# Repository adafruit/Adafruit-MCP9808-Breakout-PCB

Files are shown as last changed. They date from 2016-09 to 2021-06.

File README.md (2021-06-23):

## Adafruit MCP9808 High Accuracy I2C Temperature Sensor Breakout PCB
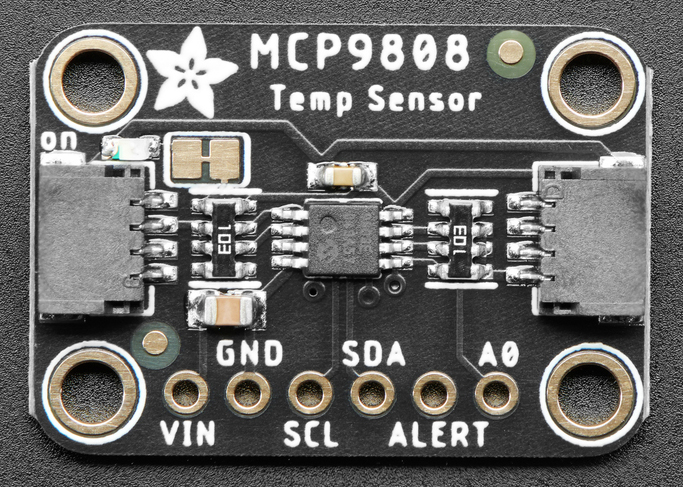
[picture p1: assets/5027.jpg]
<a href="http://www.adafruit.com/products/5027"><br/>
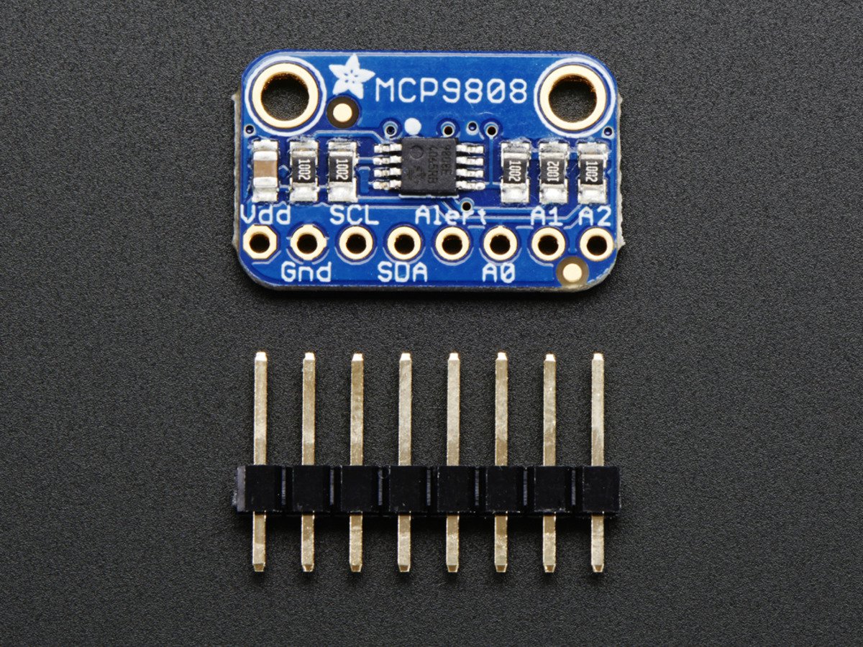
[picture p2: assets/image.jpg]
<a href="http://www.adafruit.com/products/1782"><br/>
Click here to purchase one from the Adafruit shop</a>

This I2C digital temperature sensor is one of the more accurate/precise we've ever seen, with a typical accuracy of ±0.25°C over the sensor's -40°C to +125°C range and precision of +0.0625°C. They work great with any microcontroller using standard i2c. There are 3 address pins so you can connect up to 8 to a single I2C bus without address collisions. Best of all, a wide voltage range makes it usable with 2.7V to 5.5V logic!

Unlike the DS18B20, this sensor does not come in through-hole package so we placed this small sensor on a breakout board PCB for easy use. The PCB includes mounting holes, and pull down resistors for the 3 address pins. We even wrote a lovely little tutorial and library that will work with Arduino or CircuitPython. You'll be up and running in 15 minutes or less.

PCB files for the Adafruit MCP9808 Breakout. The format is EagleCAD schematic and board layout
- https://www.adafruit.com/products/1782

### License

Adafruit invests time and resources providing this open source design, please support Adafruit and open-source hardware by purchasing products from [Adafruit](https://www.adafruit.com)!

All text above must be included in any redistribution

Designed by Limor Fried/Ladyada for Adafruit Industries.
Creative Commons Attribution/Share-Alike, all text above must be included in any redistribution. 
See license.txt for additional information.

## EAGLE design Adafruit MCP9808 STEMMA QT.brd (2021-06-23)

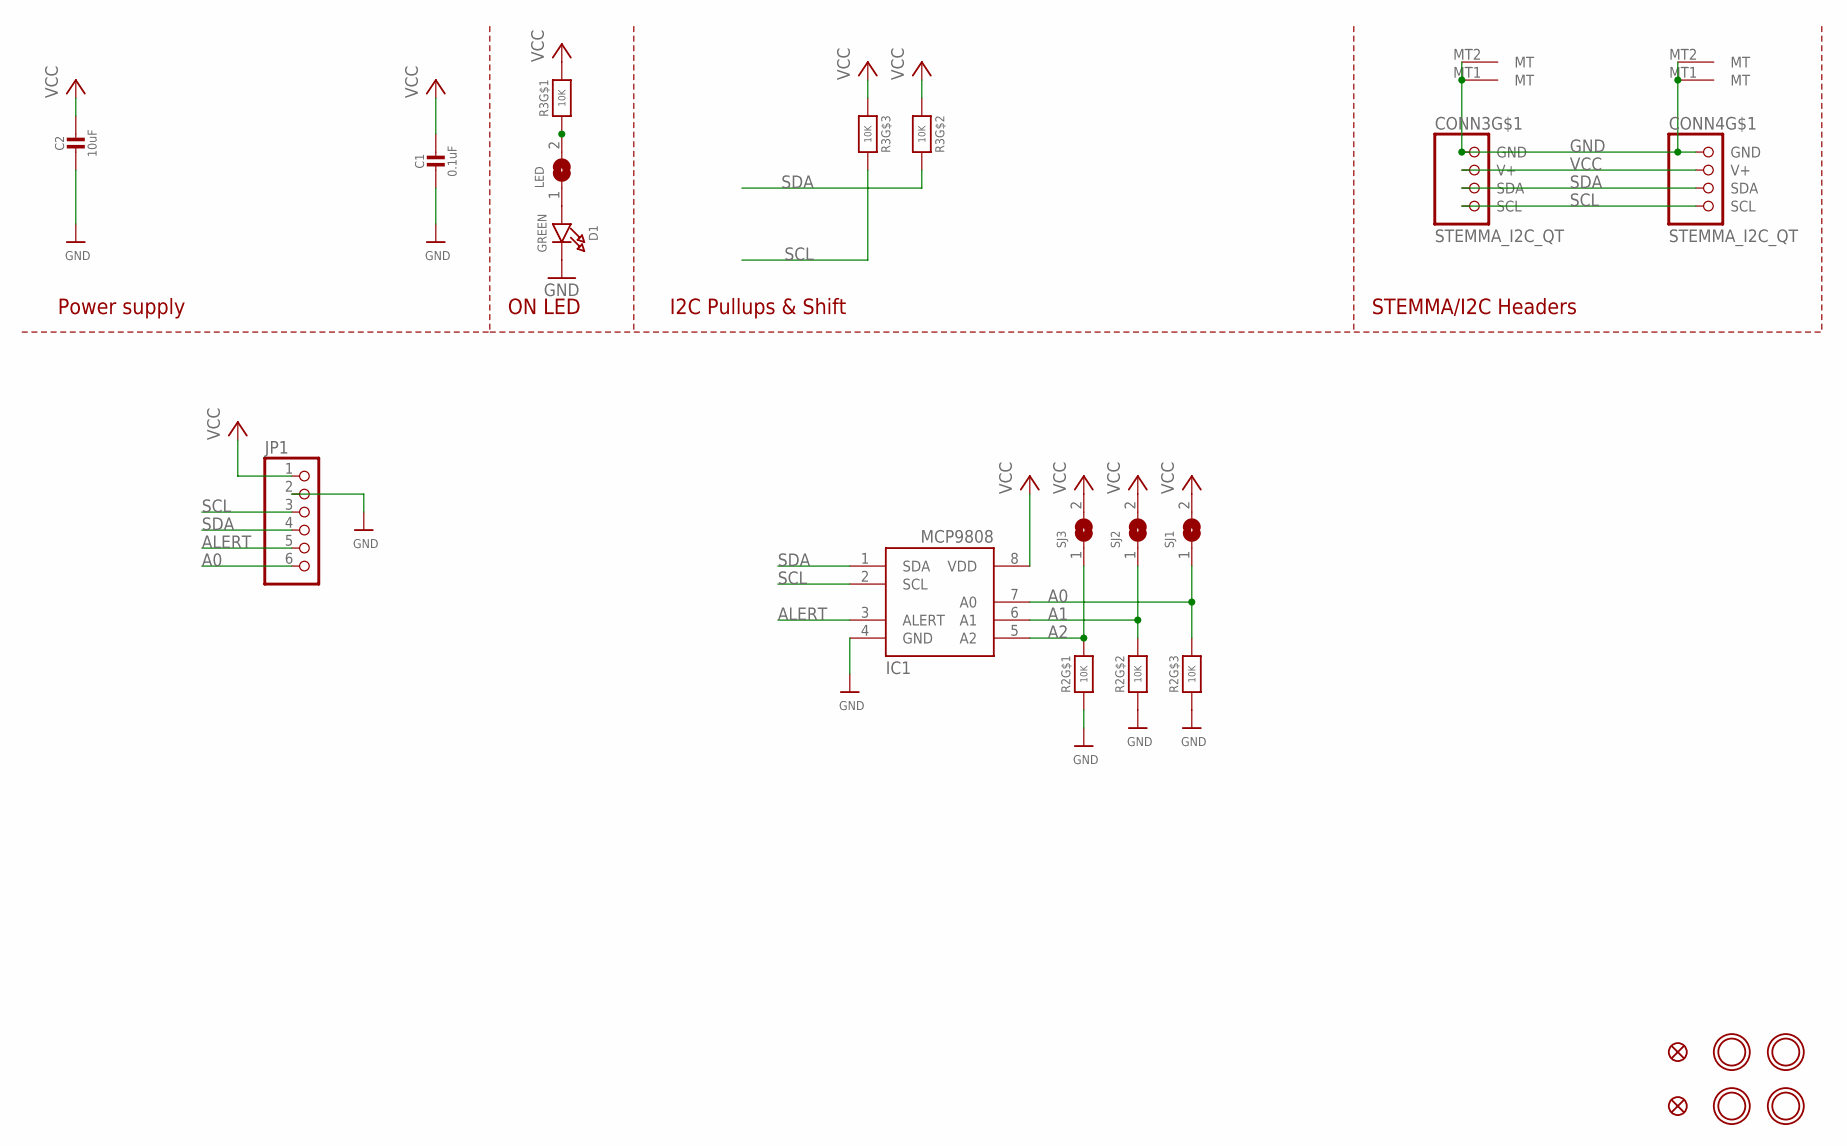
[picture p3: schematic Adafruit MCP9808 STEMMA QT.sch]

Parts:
C1: 0.1uF; 0603-NO
C2: 10uF; 0805-NO
CONN3, CONN4: STEMMA_I2C_QT; JST_SH4
D1: GREEN; CHIPLED_0603_NOOUTLINE
FID3, FID4: FIDUCIAL_1MM
IC1: MCP9808-E/MS; MSOP8_0.65MM
JP1: HEADER-1X670MIL; 1X06_ROUND_70
LED: SOLDERJUMPERCLOSED; SOLDERJUMPER_CLOSEDWIRE
R2, R3: 10K; RESPACK_4X0603
SJ1, SJ2, SJ3: SOLDERJUMPER; SOLDERJUMPER_ARROW_NOPASTE
U$1, U$17, U$19, U$21: MOUNTINGHOLE2.5; MOUNTINGHOLE_2.5_PLATED

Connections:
A0: IC1.7 (A0), JP1.6, R2.6 (2), SJ1.1
A1: IC1.6 (A1), R2.7 (2), SJ2.1
A2: IC1.5 (A2), R2.8 (2), SJ3.1
ALERT: IC1.3 (ALERT), JP1.5
GND: C1.2, C2.2, CONN3.1 (GND), CONN3.MT1 (MT), CONN3.MT2 (MT), CONN4.1 (GND), CONN4.MT1 (MT), CONN4.MT2 (MT), D1.C, IC1.4 (GND), JP1.2, R2.1, R2.2 (1), R2.3 (1)
unnamed: LED.2, R3.1
unnamed: D1.A, LED.1
SCL: CONN3.4 (SCL), CONN4.4 (SCL), IC1.2 (SCL), JP1.3, R3.6 (2)
SDA: CONN3.3 (SDA), CONN4.3 (SDA), IC1.1 (SDA), JP1.4, R3.7 (2)
VCC: C1.1, C2.1, CONN3.2 (V+), CONN4.2 (V+), IC1.8 (VDD), JP1.1, R3.2 (1), R3.3 (1), R3.8 (2), SJ1.2, SJ2.2, SJ3.2

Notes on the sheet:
I2C Pullups & Shift
STEMMA/I2C Headers
ON LED
Power supply

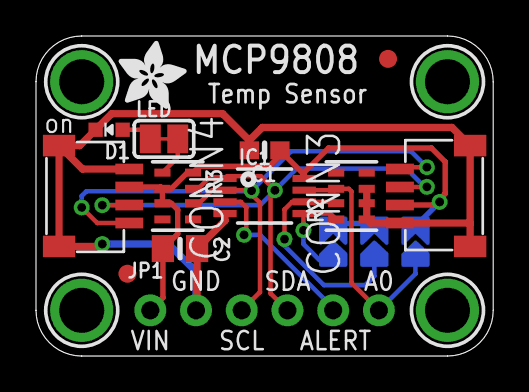
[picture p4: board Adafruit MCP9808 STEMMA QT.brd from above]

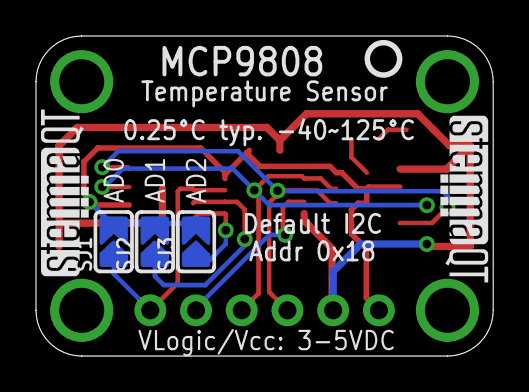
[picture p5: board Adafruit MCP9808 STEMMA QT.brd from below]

Board: 2 copper layers, 25.4 x 17.8 mm, 23 parts (6 on the bottom side), 10 nets.

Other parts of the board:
U$22: ADAFRUIT_3.5MM
U$25: PCBFEAT-REV-040
U$30, U$31: STEMMAQT

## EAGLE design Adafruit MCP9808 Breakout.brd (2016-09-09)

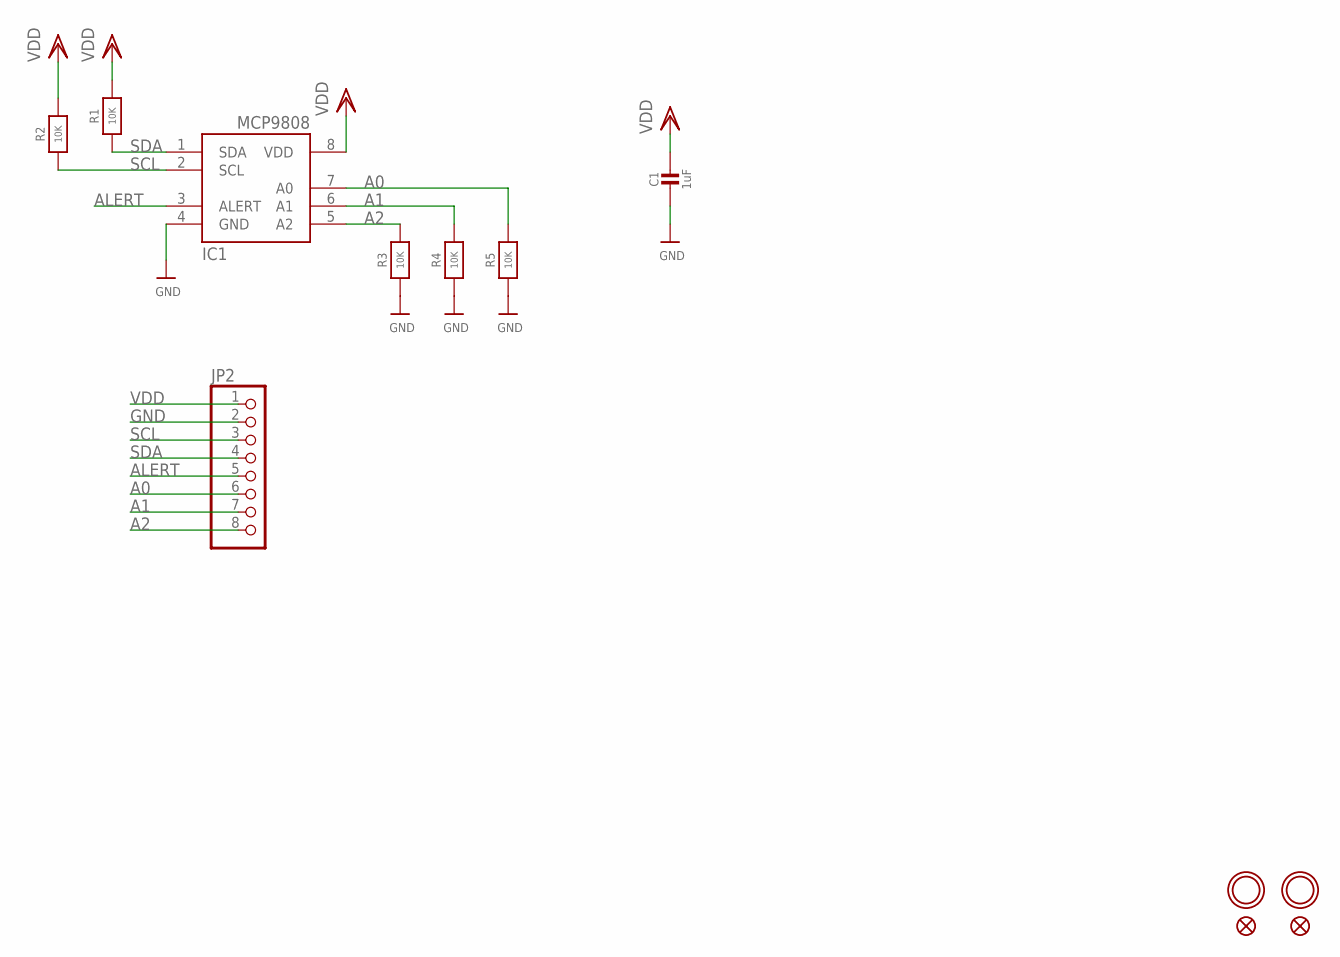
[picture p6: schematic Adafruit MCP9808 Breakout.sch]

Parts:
C1: 1uF; _0805MP
FID1, FID2: FIDUCIAL""; FIDUCIAL_1MM
IC1: MCP9808-E/MS; MSOP8_0.65MM
JP2: HEADER-1X870MIL; 1X08_ROUND_70
R1, R2, R3, R4, R5: 10K; 0805-NO
U$3, U$5: MOUNTINGHOLE2.5; MOUNTINGHOLE_2.5_PLATED

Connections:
A0: IC1.7 (A0), JP2.6, R5.2
A1: IC1.6 (A1), JP2.7, R4.2
A2: IC1.5 (A2), JP2.8, R3.2
ALERT: IC1.3 (ALERT), JP2.5
GND: C1.2, IC1.4 (GND), JP2.2, R3.1, R4.1, R5.1
SCL: IC1.2 (SCL), JP2.3, R2.1
SDA: IC1.1 (SDA), JP2.4, R1.1
VDD: C1.1, IC1.8 (VDD), JP2.1, R1.2, R2.2

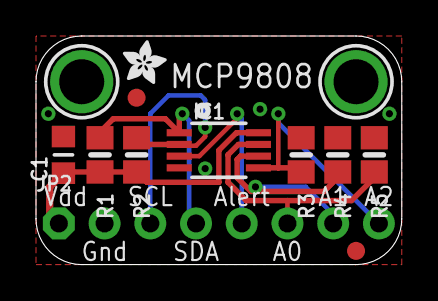
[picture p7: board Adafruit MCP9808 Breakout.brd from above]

Board: 2 copper layers, 20.3 x 12.7 mm, 13 parts (0 on the bottom side), 8 nets.

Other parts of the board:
U$4: ADAFRUIT_2.5MM

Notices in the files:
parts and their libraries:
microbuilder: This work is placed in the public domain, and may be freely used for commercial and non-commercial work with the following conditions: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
